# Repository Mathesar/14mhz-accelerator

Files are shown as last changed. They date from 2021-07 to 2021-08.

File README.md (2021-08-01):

# 14mhz-accelerator

This is 14MHz 68000 accelerator with 1MB fast ram and disable switch for the Amiga.
Tested on a rev. 5 Amiga 500. It might also work on other revisions and Amiga models but that has not been tested.
The design is licensed under CERN OHL-S V2.0

The design is a complete overhaul of a design by Livio Plos and Jorg Richter. Although based upon that design so much has been changed that it is almost like a new design.

Changes include:
* New clock doubler using an old school 4046 PLL to generate the 7MHz quadrature clock
This is more reliable than the RC delays in the original design. Alternatively the quadrature clock can
be taken from the motherboard. The latter has not been tested
* 3 input NOR's have been replaced by more common 2-input NOR's
In the process the basic design could be reduced to 4 IC's.
* some JK flipflops have been replaced by D latches.
* The E vs VMA/VPA timing has been improved for more robust write timing
* AS is now delayed before being fed to the motherboard fixing issues when the CPU does a chipset cycle after a CIA cycle.
* an optional 1Mb of zero waitstate Ranger RAM has been added to take full advantage of the 14MHz cpu.
* an optional reset timing based switch has been added to disable the ranger RAM upon boot.

## Variants
The accelerator can be build in 3 variant:
* Accelerator only
This only doubles the clock of the CPU to 14MHz. 
* Accelerator plus 1MB zero waitstate ranger RAM
The above but adds 1MB of fast RAM. This makes the accelerator about 2.7 times faster than a stock A500
* Accelerator plus 1MB zero waitstate ranger RAM plus disable circuit
The above but adds a timer based disable option for the RAM. By holdiing ctrl-amiga-amiga down for more 
than 5..6 seconds the RAM is disabled. It is enabled again on the next (less than 5..6 seconds) reset cycle

## Building hints
* use turned/machined pins only for the host connector!
The thick part is soldered on the accelerator, the thin part goes into the 68000 socket on the motherboard.
Makes sure to use the full length of the pins (only solder the tips in the accelerator board) so the accelerator sits above the Kickstart.
* an MC68HC000 (HCMOS version) is preferred as it uses less power and has better drive. This might also help with EPROM Kickstarts on a rev. 5 motherboard.
* The PLL might needs some tuning to provide a 50% dutycycle clock. 
Tuning is done by making the value of R3 slightly smaller or larger until testpoint J2 shows a nice
50% / 14MHZ clock signal. An oscilloscope works best here but alternatively a simple multimeter can be used to adjust the DC voltage
to read half the VCC value. (thus typically about 2.5V if VCC is **really** 5V)
* Alternatively the CDAC signal from the motherboard can be used. No tuning needed but untested at this point.

Here is a picture of the most basic variant (accelerator only) for reference purposes:
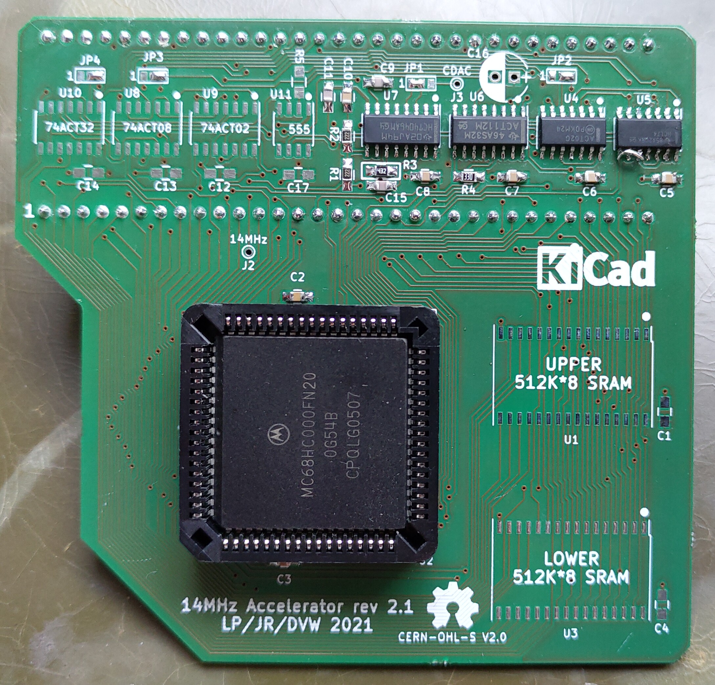
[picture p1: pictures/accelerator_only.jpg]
Accelerator only


And here a picture of what a complete build should look like:
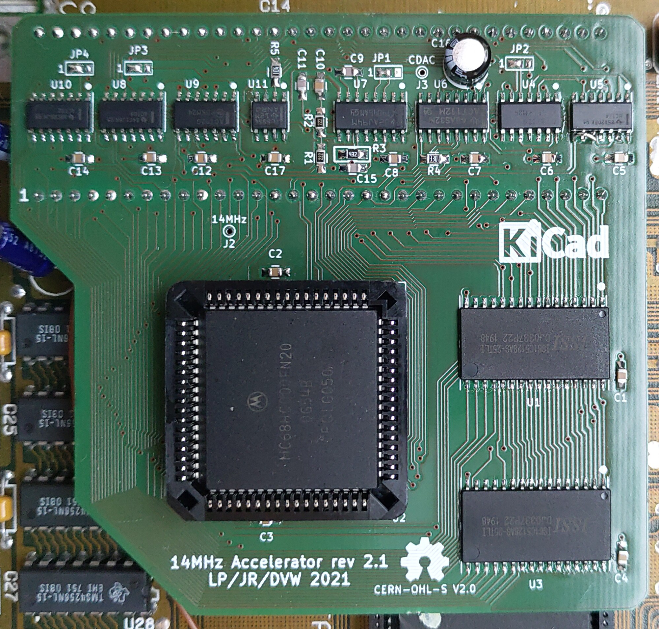
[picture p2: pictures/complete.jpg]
complete build


Have fun!

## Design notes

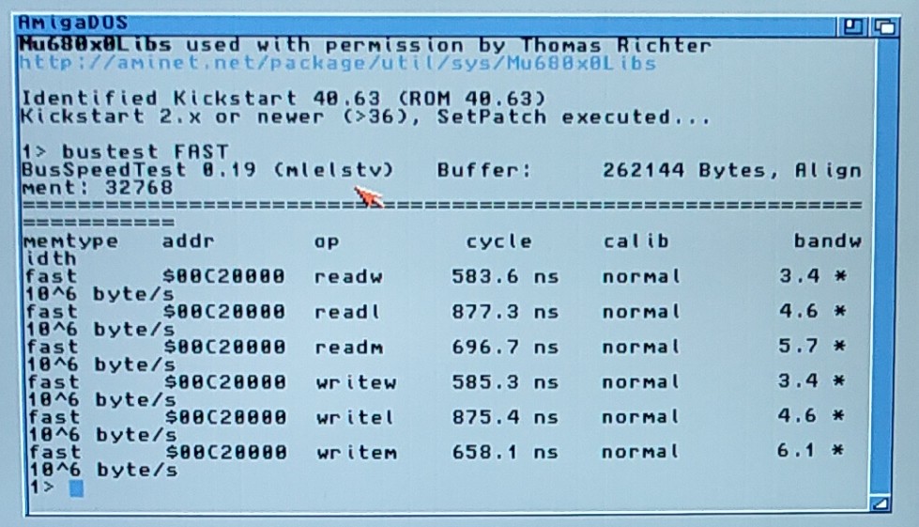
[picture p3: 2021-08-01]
pictures/IMG_20210704_210522~2_copy.jpg

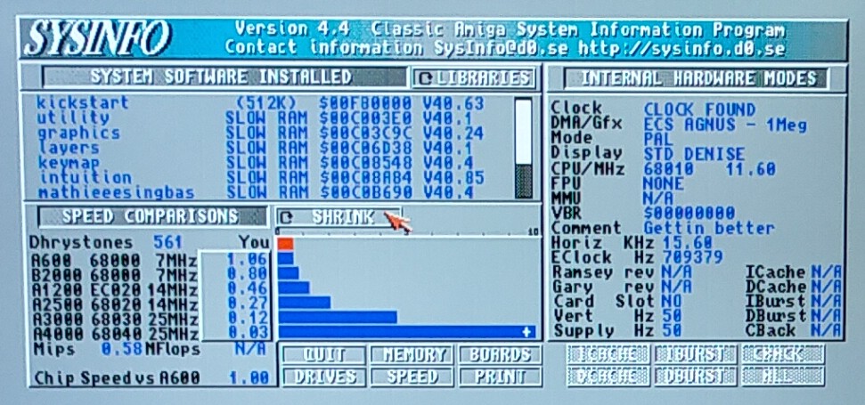
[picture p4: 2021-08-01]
pictures/IMG_20210704_210146~2_copy.jpg

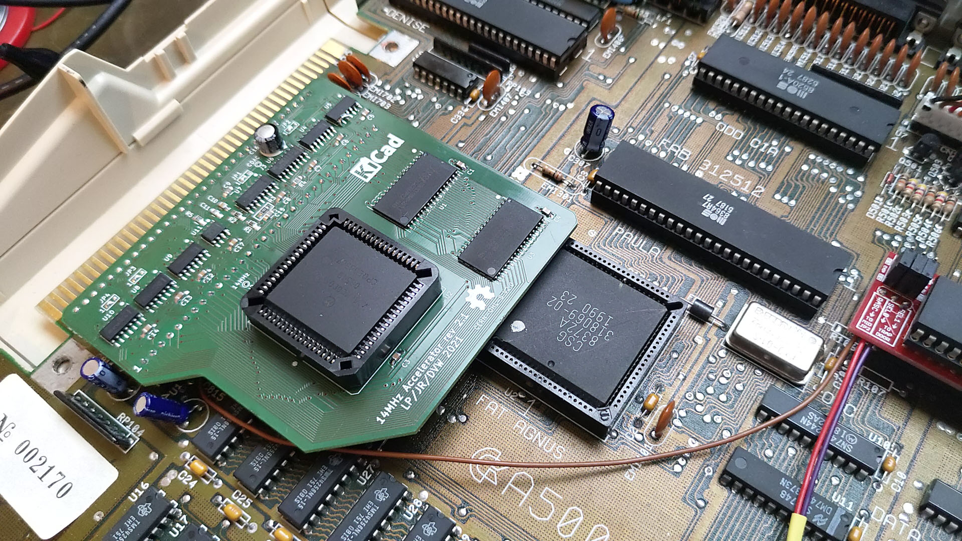
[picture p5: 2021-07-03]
pictures/mounted in A500.jpg

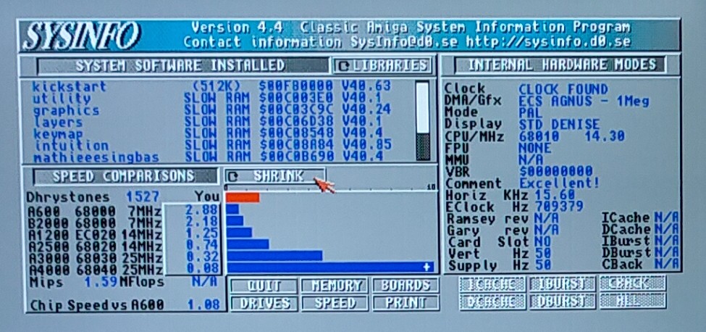
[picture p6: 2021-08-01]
pictures/IMG_20210704_205705~2_copy.jpg

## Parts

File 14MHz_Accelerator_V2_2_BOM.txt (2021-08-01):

RefDes		Partnumber	Remarks
#####################################################################################

U1,U3		512K*8 SRAM	IS61C5128AS-25TLI or similar 5V type

U2		MC68HC000	PLCC-68 Thru Hole socket 

U4,U9		74ACT02		U4 can be 74HCT02

U5		74HCT74		must be HCT

U6		74ACT112	

U7		74HCT4046	also 74HC4046 if CDAC not used

U8		74ACT08		

U10		74ACT32		

U11		TLC555CD	or any other CMOS 555

J1		2 * 32pinstrip	machined pins only. for example 2 * TS-132-T-A 

C1,C2,C3,
C4,C5,C6,
C7,C8,C10,
C12,C13,C14,
C17		100n		0805 

C9,C15		100p		0805

C11		22p		0805

C16		47u/16V		2.5mm radial 6.3mm dia

R1,R2		2K2		0805

R3		4K3		0805 (might need tuning)

R4		33 Ohm		0805	

R5		100K		0805

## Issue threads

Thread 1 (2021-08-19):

Jumper On U5

ozkanocakli, 2021-08-19:
is it a fix, or is it a  temporary jumper that forgot on it

Mathesar, 2021-08-20:
The pictures are from revision 2.1. That revision need a small patch hence the jumper wire on U5.
The current design is revision 2.2 fixed that issue and needs no patches or jumper wires to work.

ozkanocakli, 2021-08-20:
Thanx,

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

Closed 2021-08-20.

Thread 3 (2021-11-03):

Other address range for A600/2MB Chip-RAM compatibility?

Lalarian, 2021-11-03:
Hello!

I wondered, if it would be possible to add a jumper for changing the address range?
While was searching for affordable solutions, for making the A600 a capable WHDLoad machine (which would require FastRAM and an 68010 for the quit-key-feature), I was also including A500 expansions into the search, since
there are cheap adapters that disable the A600's onboard 68k (like Lemaru's PLCC2DIP), which allow plugging 68K DIPs into the A600.

So I found a video about your new accelerator on YouTube and then the thread on abime.
There I read you used the ChipRAM range for not having to bother with autoconfig.
Putting an 68010 in the socket of this board shouldn't be a problem, as it's fully compatible.

So the only problem would probably be the conflict with an A600 that has 2MB ChipRAM overall from the trapdoor slot.
I think autoconfig isn't too important (is it?), as we could automatically add the RAM of the board from startup-sequence/user-startup, using Amiga's 'addmem' tool, which would basically always be possible, when booting the user's own system from HD/CF/SD before starting WHDLoad.

So, would it be possible to place the board's RAM as 8MB-FastRAM from 0x200000 to 0x9FFFFF? Maybe just by swapping some address lines around using a jumper (as this project is of course intended to stay affordable)?
Thank you! :)

Mathesar, 2021-11-06:
Hello Lalarian,

The 1MB ram on this board is assigned the $C00000. The optional 1MB chipram in the A600's trapdoor slot is assigned to $100000. So there should be no conflict!

Lalarian, 2021-11-06:
Thank you! That's great news!
So I am gonna try to upgrade my 600, soon! I will report when I'm done, just for confirmation!
:)

Closed 2021-11-06.

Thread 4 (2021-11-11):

Platform agnostic?

dlxmax, 2021-11-11:
Is there anything that would keep the accelerator-only version from working on another 68k platform, such as a Mac or Atari?

Mathesar, 2021-11-14:
Probably only the RAM. I don't know the memory layout of the ST or the Macintosh but I can imagine that the $C00000..$CFFFFF range is already taken. Other than that I see no fundamental reason why it wouldn't work. Best way to find out is to try it out with an accelerator-only version.

dlxmax, 2022-01-12:
I measured for putting one of these in a Mac Plus, but the board is at least 3mm too long to fit, interfering with the power connector. Trying to beat it with height would result in case interference. I suppose the PCB could be shaved at the bottom, as it appears those lines are for the memory chips...but that's such a dirty hack lol. I really hoped to give it a go!

Closed 2022-02-10.

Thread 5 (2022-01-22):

Disable switch?

MarkieV, 2022-01-22:
Hi there

In the readme it says 'and disable switch for the Amiga' I looked several times at the schematics,
but I can not find a switch.
Do I have to make something with two 74F157 switches (like in the old version) to switch between
7MHz and 14MHz? or do I overlook something.

I would like to make a small PCB that sits under the 68000 with only the clock doubler as I already
have 8MB fastram.

Grtzz  Mark

Mathesar, 2022-01-25:
On page 3 of the schematic you can see a 555 timer based circuit. This is the disable switch that works by holding ctrl-amiga-amiga key combo down for more that 6 seconds or so.
However, it does not disable the clock doubler but only the ranger (fast) ram. In practice this has virtually the same effect as disabling the clock doubler.

Mathesar, 2022-01-25:
One more thing. Combining this accelerator with fast ram sitting on the Amiga bus will not be very fast as that ram does not run at the full 14MHz. My guestimate is that it will make your Amiga about 1.5 times faster than stock.
(based on this text: [http://www.cucug.org/amiga/amiinfo/reviews/Accelerator14M.txt](url)

Closed 2022-01-25.

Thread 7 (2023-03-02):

Sysinfo shows CPU@11.30 Mhz and not 14 Mhz.

felmur, 2023-03-02:
Hi Mathesar and thanks for this beautiful project.

I had the PCB made by PCBWay, then I ordered the components for the accelerator only (CPU and the 4 ICs and those few smd passive components).
After having soldered everything, I tried to mount it in my A500 rev6, already equipped with this ram expansion, 2MB version (0.5 chip, 1.5 fast):
https://amigastore.eu/en/710-amiga-500-512kb2mb-memory-expansion-rtc.html#/
When I run SysInfo it calculates a clock speed of 11.30 Mhz (and not 14 Mhz) and a very small increase in performance (1.04 vs A600).
What do you think?
Regards.

Mathesar, 2023-03-03:
Hi Felmur,

The 2MB trapdoor expansion from amigastore.eu gives you 1.5MB "pseudo" fast RAM. Not real fast RAM. As a result the 14MHz CPU can not run at full speed. This accelerator only reaches its full speed when the 1MB of local fast RAM is also populated. Without it, you will only see this small speed increase that you see now.

felmur, 2023-03-03:
Hi Mathesar,
In fact, by removing the expansion, the speed measured by SysInfo goes up to 11.70 Mhz and the performance goes up to 1.05 vs A600. Nothing changes if I use the PC CDAC instead of the accelerator internal clock.
If so, it's not worth using this booster without installing ram memory as well.
Well, patience. Thanks for the reply.

Mathesar, 2023-03-03:
I wouldn't really worry about 11.70 MHz vs 11.30 MHz, that is just noise.
The RAM expansion won't make your system slower. You can install the RAM memory on the accelerator board and still use the 2MB expansion. However, the first 1Mb of slow ram won't be used anymore as it will be overruled by the accelerator RAM.
So, you keep the same amount of memory (2.5Mb total) but the first 1Mb of slow RAM will turn into real fast RAM.

felmur, 2023-03-03:
Thanks Mathesar, I had already started looking for the rest of the components to complete the accelerator + ram.

felmur, 2023-04-24:
Due to an error in the order of the remaining components from Chinese companies, I had to wait until today to be able to finish the accelerator, which I just did. And... It Works! Sysinfo tells me that my A500 is now 2.70 times faster than an A600 and 1.22 times faster than an Amiga1200. Thanks for this wonderful project!

Mathesar, 2023-05-03:
Good to hear!
Enjoy!

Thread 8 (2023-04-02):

simple 8MB option (AS6C6416)

raszpl, 2023-04-02:
AS6C6416 https://www.alliancememory.com/wp-content/uploads/pdf/Alliance%20Memory_64M_AS6C6416-55TIN%20v1.0%20July%202017.pdf
3.3V only (max Vcc 4.6V) so author of Parciero went full insane mode https://hackaday.com/2021/01/08/the-amiga-1000-still-receiving-new-peripherals-35-years-later/#comment-6309849 but it works. To be on a safe side there should be $1 SN74LVC16T245 in front of it.
$28 so not terrible https://www.digikey.com/en/products/detail/alliance-memory-inc/AS6C6416-55TIN/7791412 considering two IS61C5128AS is already $10.

Mathesar, 2024-08-13:
Could be done I guess. The address decoder has to be changed of course, as well the RAM CS  and OE / WR strobes as these are currently layed out for a high byte and low byte RAM chip. Also, the RAM would have to be added via a command in the startup sequence as it will not be auto recognized.

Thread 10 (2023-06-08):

Compatible with trap door 512k RAM expansion on A500?

alexispurslane, 2023-06-08:
I'm brand new to this stuff, and reading through the forum thread where this project was introduced, it seemed like this board puts the onboard RAM in the same address location as slow RAM, which would override the slow RAM trap door expansion, while also not _really_ being slow RAM, meaning it isn't accessible to the chips, thus limiting my machine to 1.5MB instead of 2MB, and (more importantly) making it impossible to do the Fat Agnes ECS mod to my A500 if I'm using it. Is this right or am I completely off-base? I think I'm probably wrong given your sysinfo screenshot.

Also, I recently bought a print of this board (and some ICs) off eBay, and it comes with a 68020, has anyone had any luck with using an 020 with this board before?

alexispurslane, 2023-06-09:
Closed bc answer is obvious: 020 won't work (I misread what I'd bought anyway), and yes, the 1MB of "slow" fast RAM on the board will shadow the 512k of slow RAM in a trap door expansion, so best to turn that into chip RAM with the Obese Agnus ECS mod.

Closed 2023-06-09.

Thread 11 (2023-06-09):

Is this compatible with *any* internal hard drive IDE expansion/card/etc?

alexispurslane, 2023-06-09:
If the issue with the A590 is DMA and it having its own fast RAM, won't that be an issue for any hard drive?

Mathesar, 2024-08-13:
Don't know really. It works with harddrive adapters of my own design (non-booting IDE and SD) but I haven't tested it with any other devices. The only issue for sure has to do with DMA. Other issues (if any) will have to be found out.

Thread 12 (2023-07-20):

enhancement: 16bit ram chip support

pluspeople, 2023-07-20:
Love the design (despite the DMA issue), would it be possible to enhance the design to utilize 16bit sram chips instead of 2x 8bit chips ?
This would give the following advantages:
- It would be possible to fit 2x 4mbit 16bit chips (1.75 addressable) without having to increase pcb size (ok tsop-44 is 5mm longer than tsop-32)
- One could choose to install either 1 or 2 chips (more options / choice)
- If only 1mb is wanted as then only one ram chip needs to be fittet (enhanced simplicity)
- As of writing a 4mbit 16bit chip costs 7.07euro vs 8.50euro for 2x 4mbit 8bit chips (slightly cheaper)

As an example I have been looking at the AS6C8016-55ZIN chip which is 5v compatible, and 55ns speed (I believe it only need to be 70ns or better to work fullspeed at 14mhz?)

Mathesar, 2024-08-13:
As commented in another issue, it could be done. However, quite some stuff would need to be changed. The address decoder has to be changed of course, as well the RAM CS and OE / WR strobes as these are currently layed out for a high byte and low byte RAM chip. Also, the RAM would have to be added via a command in the startup sequence as it will not be auto recognized.

Closed 2024-08-13.

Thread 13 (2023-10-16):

Newly built, no 1mb ranger memory reported

opengiveback, 2023-10-16:
Hi, thanks for the design.

I built one configured with all the circuits, and it worked right away. However, no ranger RAM is being reported, and measuring voltage on J2 always gets me 2.57V.

Then I found, my jumper JP2 wasn't soldered properly (all three shorted), and some solder was shorting pins of U4. However, after fixing it, still does not have any of the accelerated RAM, 1.10 max speed improvement to Amiga 600 in SysInfo, and reports 12MHz consistently.

I'd have to ask, the possibility of RAM itself not working is not what is causing the ranger RAM not to be there, right? It's some logic IC that actually reports the ranger RAM on init that's at fault? And if the RAM was faulty, it would simply freeze?
Or should I try with other RAM chips?
Or perhaps, something else entirely needs to be done to make it work? All the jumpers are shorted at pin 1 (left).

Thanks in advance

P.S. I intend to build and sell at least 10 of them, and give back 15% of the profit to the author, as per my OpenGiveBack.org idea :)

Mathesar, 2023-10-16:
The Amiga scans the ranger memory during boot time. So as it is not detected it does not use it. The computer won't freeze.
I would suspect the logic IC's that decode the memory addresses for the memory so U8/U9/U10. Check all solder joints, shorts, etc. It could also be the NE555 circuit that disables RAM. What is the level on pin 3 of U11? It should be low. You could also try setting JP4 to 2-3 for testing to disable the NE555 circuit.

opengiveback, 2023-10-18:
Triple checked all/touched up on all the relevant solder joints, pin 3 of U11 showed 0.05V (or was it 0.5V), so low, and also disabled NE555 by setting JP4 to 2-3. And the ram still was not there upon booting.

Then I changed the memory chips, for the other ones I ordered (was ALLIANCE AS6C4008-55SIN chips, then tried with HM628512CLFP-7). With the JP4 set to 2-3. And still the same result as at the start, Accelerator works, but none of the ranger RAM detected.

So, I guess the only conclusion is, some logic circuit is not working (U8, U9, U10), and needs to be replaced?

Could I test at least the NE555 by having 512KB slow RAM in expansion slot, and trying to see that slow RAM reported when holding reset keys for 6, 7 seconds, and JP4 is set to 1-2? (Because I couldn't see it before, whether held the combination for 7 seconds or not)... It should have the expansion port slow 512KB ram working now when the JP4 is set to 2-3, correct? And yet, it again boots into workbench and shows only the 512KB chip RAM, in AmiTestKit and SysInfo also. I cant understand why that would be? A pin in the CPU socket perhaps, but they all were crisp as was the ones on the new MC68HC000....

I shall try soldering another example on a different PCB, to rule out PCB manufacturing faults or a single logic chip of the ordered batch being faulty. But if you have any idea on what could be the problem with this one, I would appreciate it highly.

opengiveback, 2023-10-18:
After checking on the type of memory chips, the one you listed in the BOM is a TSOP II, and both of these are TSOP I (sTSOP), the pinout is very different. So it seems it was wrong type of memory chips that was the issue. First chose wrong extension of the model, then ordered alternative for wrong chip. Surely the wrong pinout also causes the problem with unadressable expansion port slow RAM.

I see other manufacturers have same pinout in sTSOP and TSOP II... actually the HITACHI HM628512C I used, has almost same pinout as the ISSI IS61C5128AS-25TLI from the BOM, except address lines A18 and A17 are in each other's places, which being 8 bit memory I didn't think it should matter. So I shall make another example with the HITACHI chips, and see how that goes...

opengiveback, 2023-11-20:
Update, resoldered RAM chips, stopped turning on, unsoldered them again, started working without RAM again. Soldered another, with new chips, presoldered pads, more careful to be sure all pins connected good, the other example refuses to turn on also, black screen, waiting for some Cypress chips from your forum link to arrive, with exact dimensions.

opengiveback, 2023-11-28:
Hi, so the Cypress RAM arrived, soldered it on, now all works great! :)

Thanks for the replies, and please disclose paypal email or similar means for me to donate the 15% of earnings from sold examples of this great design, as per OpenGiveBack.org.

Mathesar, 2023-12-02:
> Hi, so the Cypress RAM arrived, soldered it on, now all works great! :)
>
> Thanks for the replies, and please disclose paypal email or similar means for me to donate the 15% of earnings from sold examples of this great design, as per OpenGiveBack.org.

Hi Opengiveback,

You had quite a journey with your build. I'm sorry I couldn't check your RAM pinouts before you tried. But luckily it all works now!
And no donations please, this design is free!

Closed 2023-12-01.

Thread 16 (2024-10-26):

Confirmed working with an adapter on a A600

federicopitto, 2024-10-26:
Hello Mathesar. Thank you for this great project.

I finally got the accelerator working on his minimal configuration istalled on a A600 rev 1. It took me several tries and troubleshooting red herrings. I used LemaruX plcc to dip64 adapter to bridge the accelerator to the main board https://github.com/LemaruX/Amiga-A600-68k-PLCC2DIP-v2

Here's some photos of the setup and sysinfo

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

Sysinfo reports 18mhz but my cheap oscilloscope says the clock is at 14.20mhz

It was really difficult to tune the clock to a frequency stable enough to make the A600 initialize or complete the workbench boot. The diagROM ran no matter how unstable the clock, but the kickstart rom needed some fine tuning of the clock with the oscilloscope before even attempting to properly boot and read from the IDE device.
As you can see I installed a variable resistor in place of R3. Don't know if that was the cause oor the solution of my woes.

In my attemts, I tried using the CDAC signal directly soldering a wire from the motherboard to the proper accelerator input (and changing the jumper accordingy). I did not see any substantial difference in the stability of the input or the output.

A couple of notes:

Using version v2 of the adapter prevents the A600 case to close down.Version V1 of the adapter place the acceerator in a better spot, closer to the keyboar connector. The problem using that version is that V1 lacks the right screw-mount to clamp down the "vampire" socket tight enough against the onboard 68000 chip. I need to modify the adapter project and make it as long as the V1 version, but add back with the 4 screwmount needed to clamp it down to the HDD motherboard cutout.

I don't plan to have the ram installed right away as I want to test it further adding 4mb fastram through a PCMCIA ram card (still to be built). Alternatively I could fork your project and build the PLCC adapter directly to the accelerator board, but that may be a little too difficult considering my limited capabilities on circuit and PCB design.

Keep up the good work!

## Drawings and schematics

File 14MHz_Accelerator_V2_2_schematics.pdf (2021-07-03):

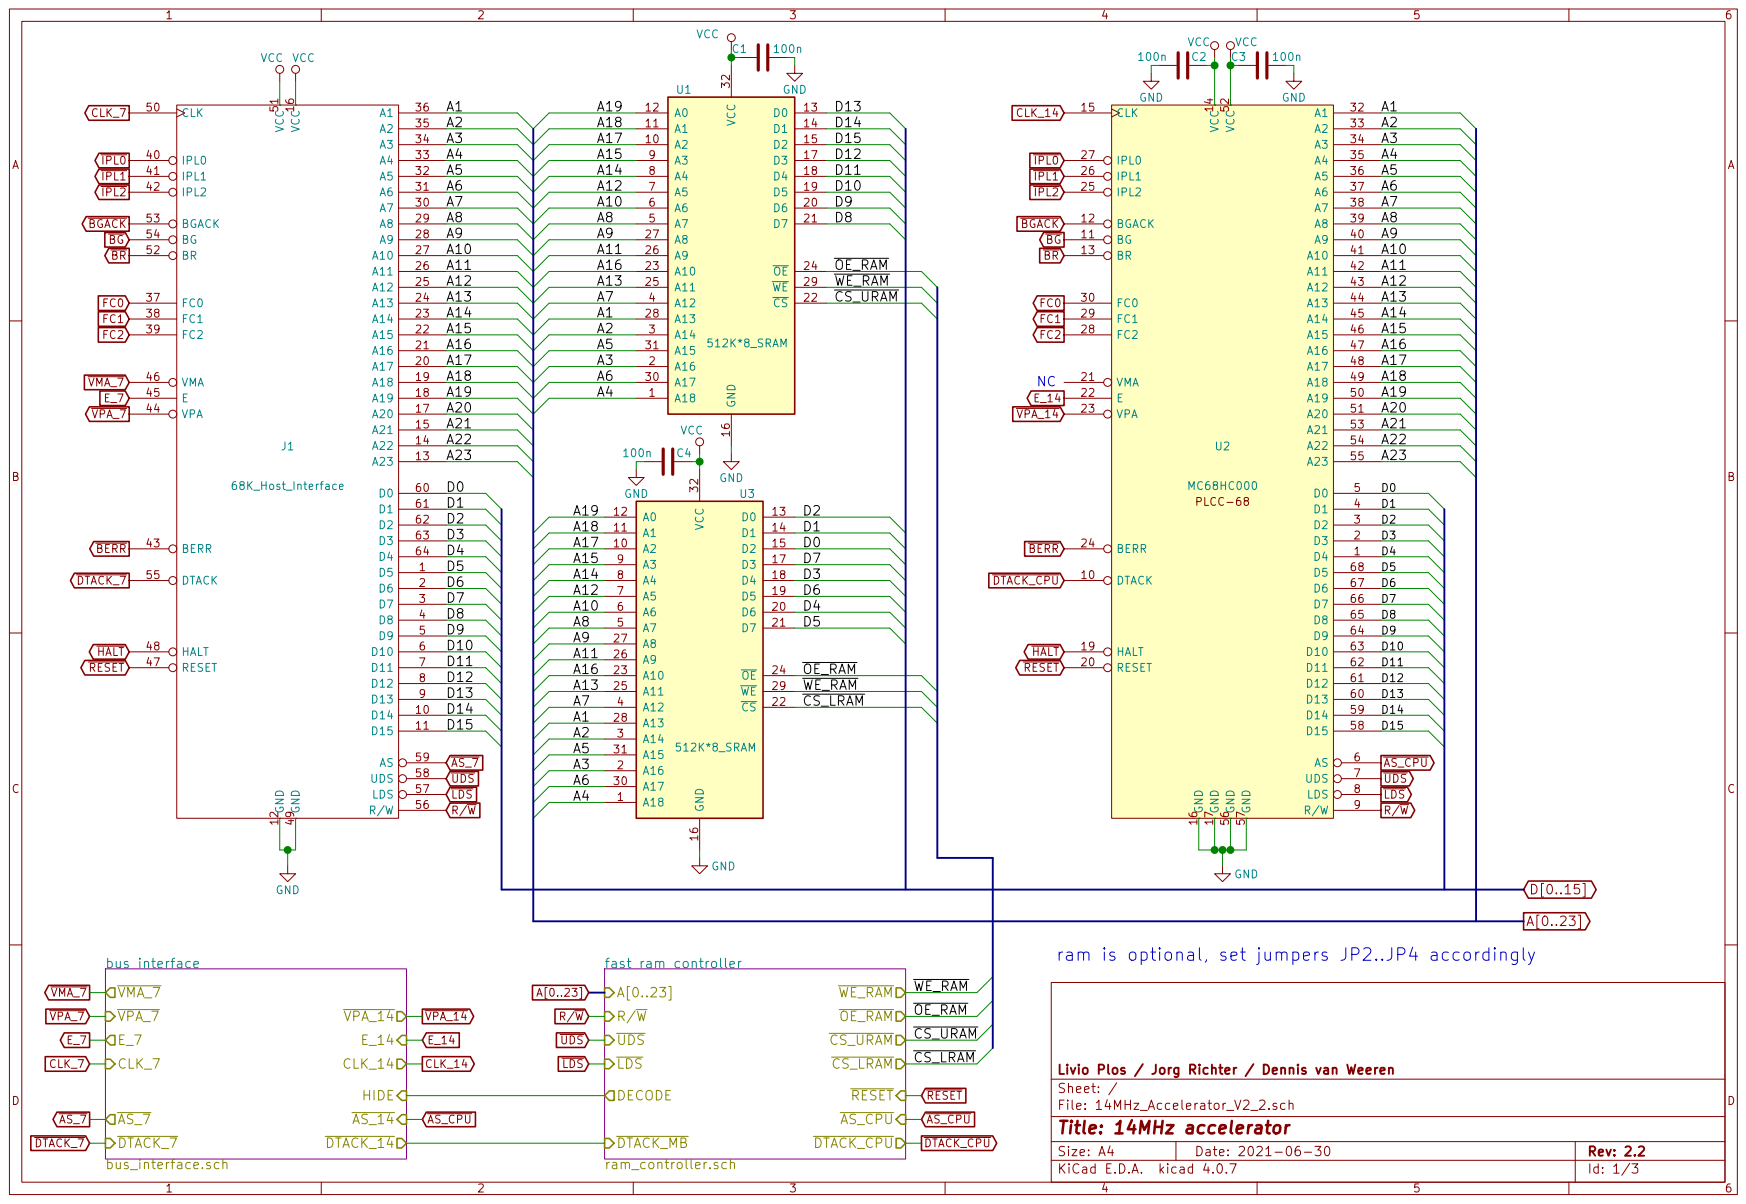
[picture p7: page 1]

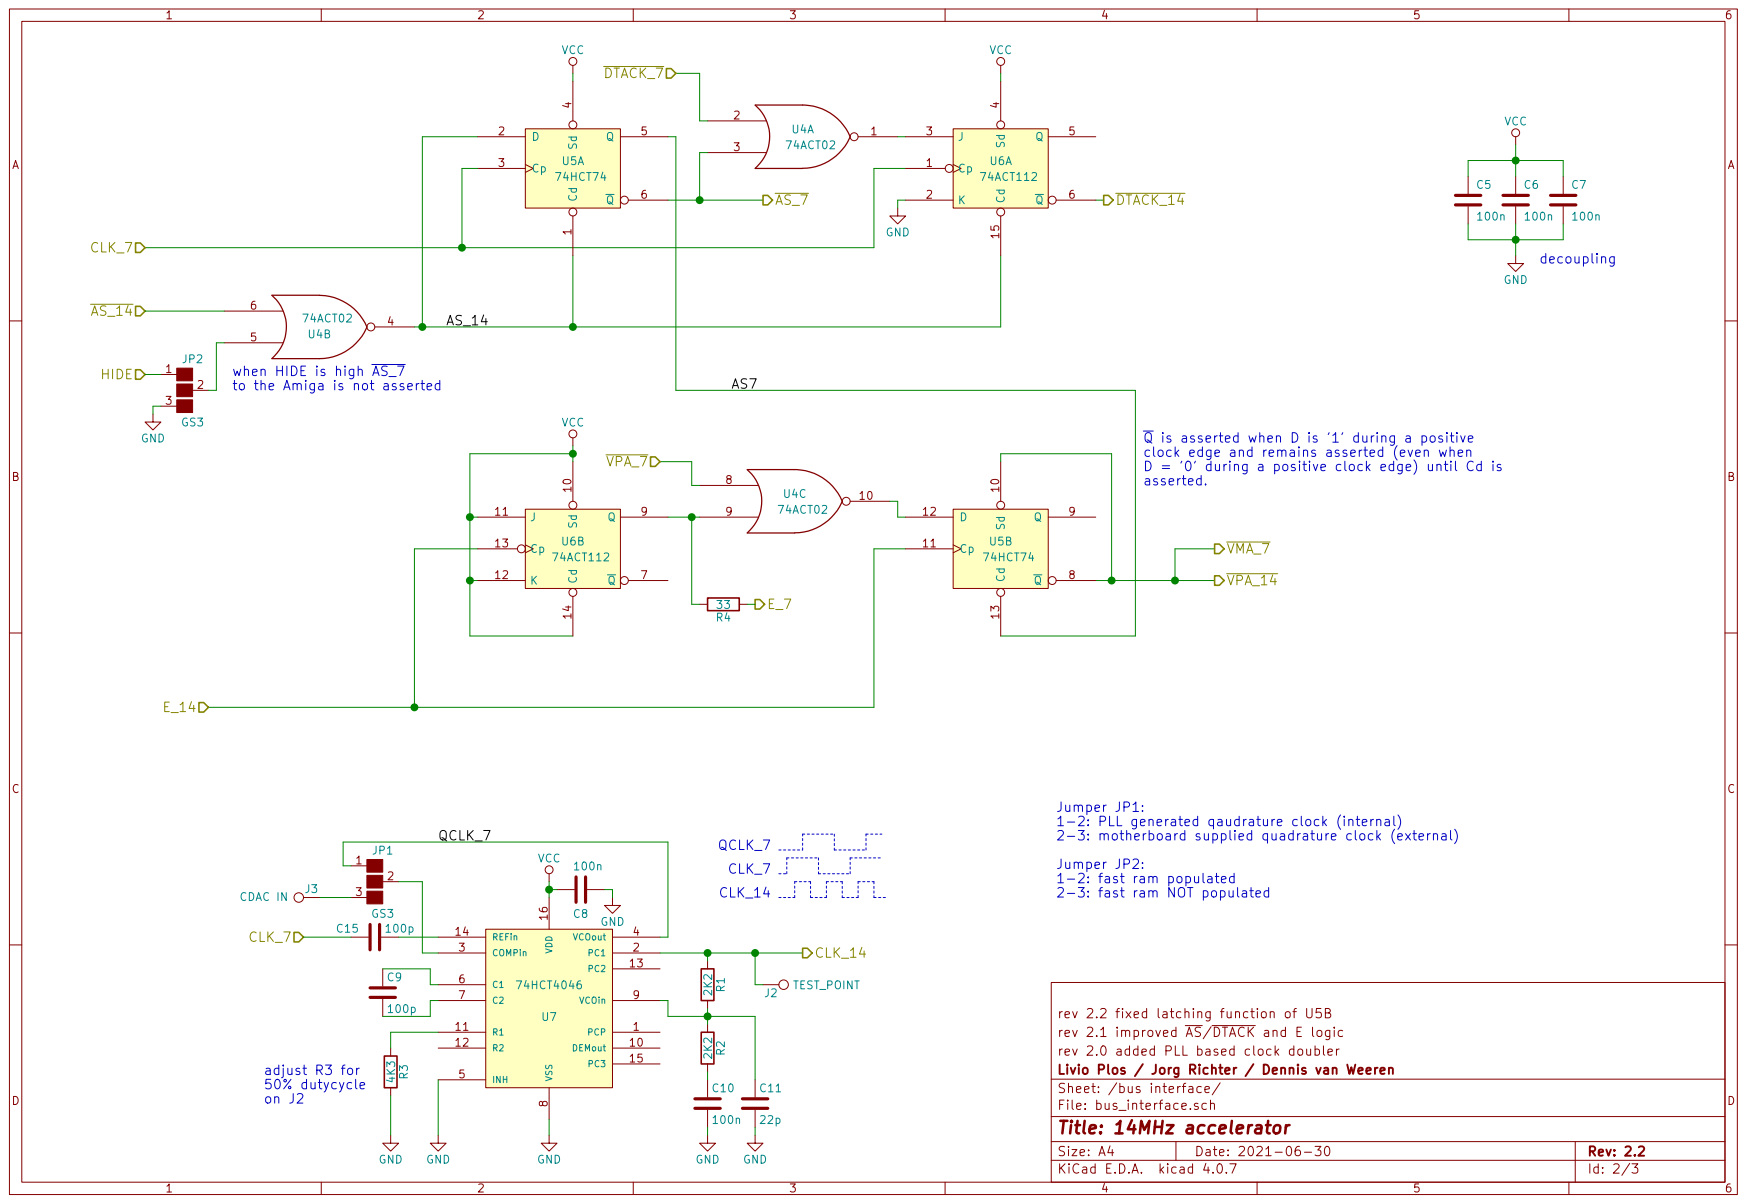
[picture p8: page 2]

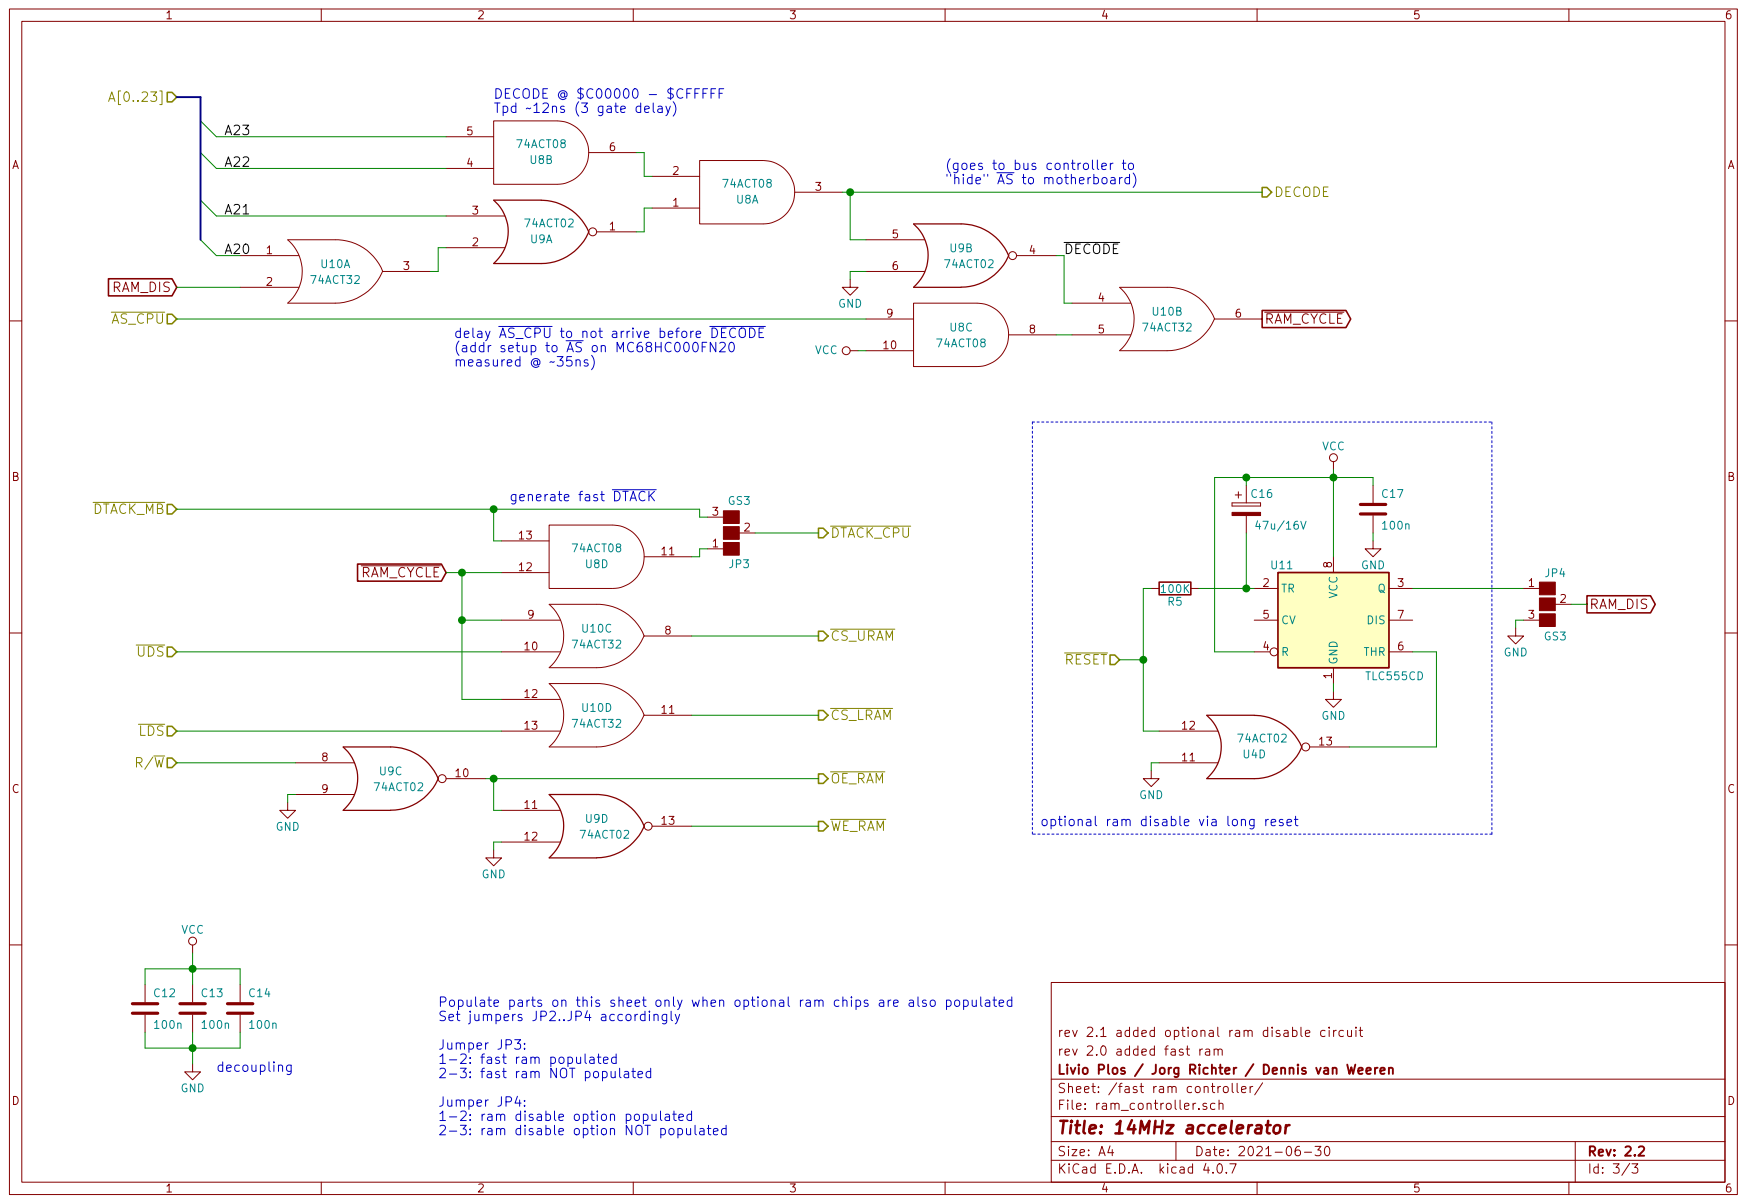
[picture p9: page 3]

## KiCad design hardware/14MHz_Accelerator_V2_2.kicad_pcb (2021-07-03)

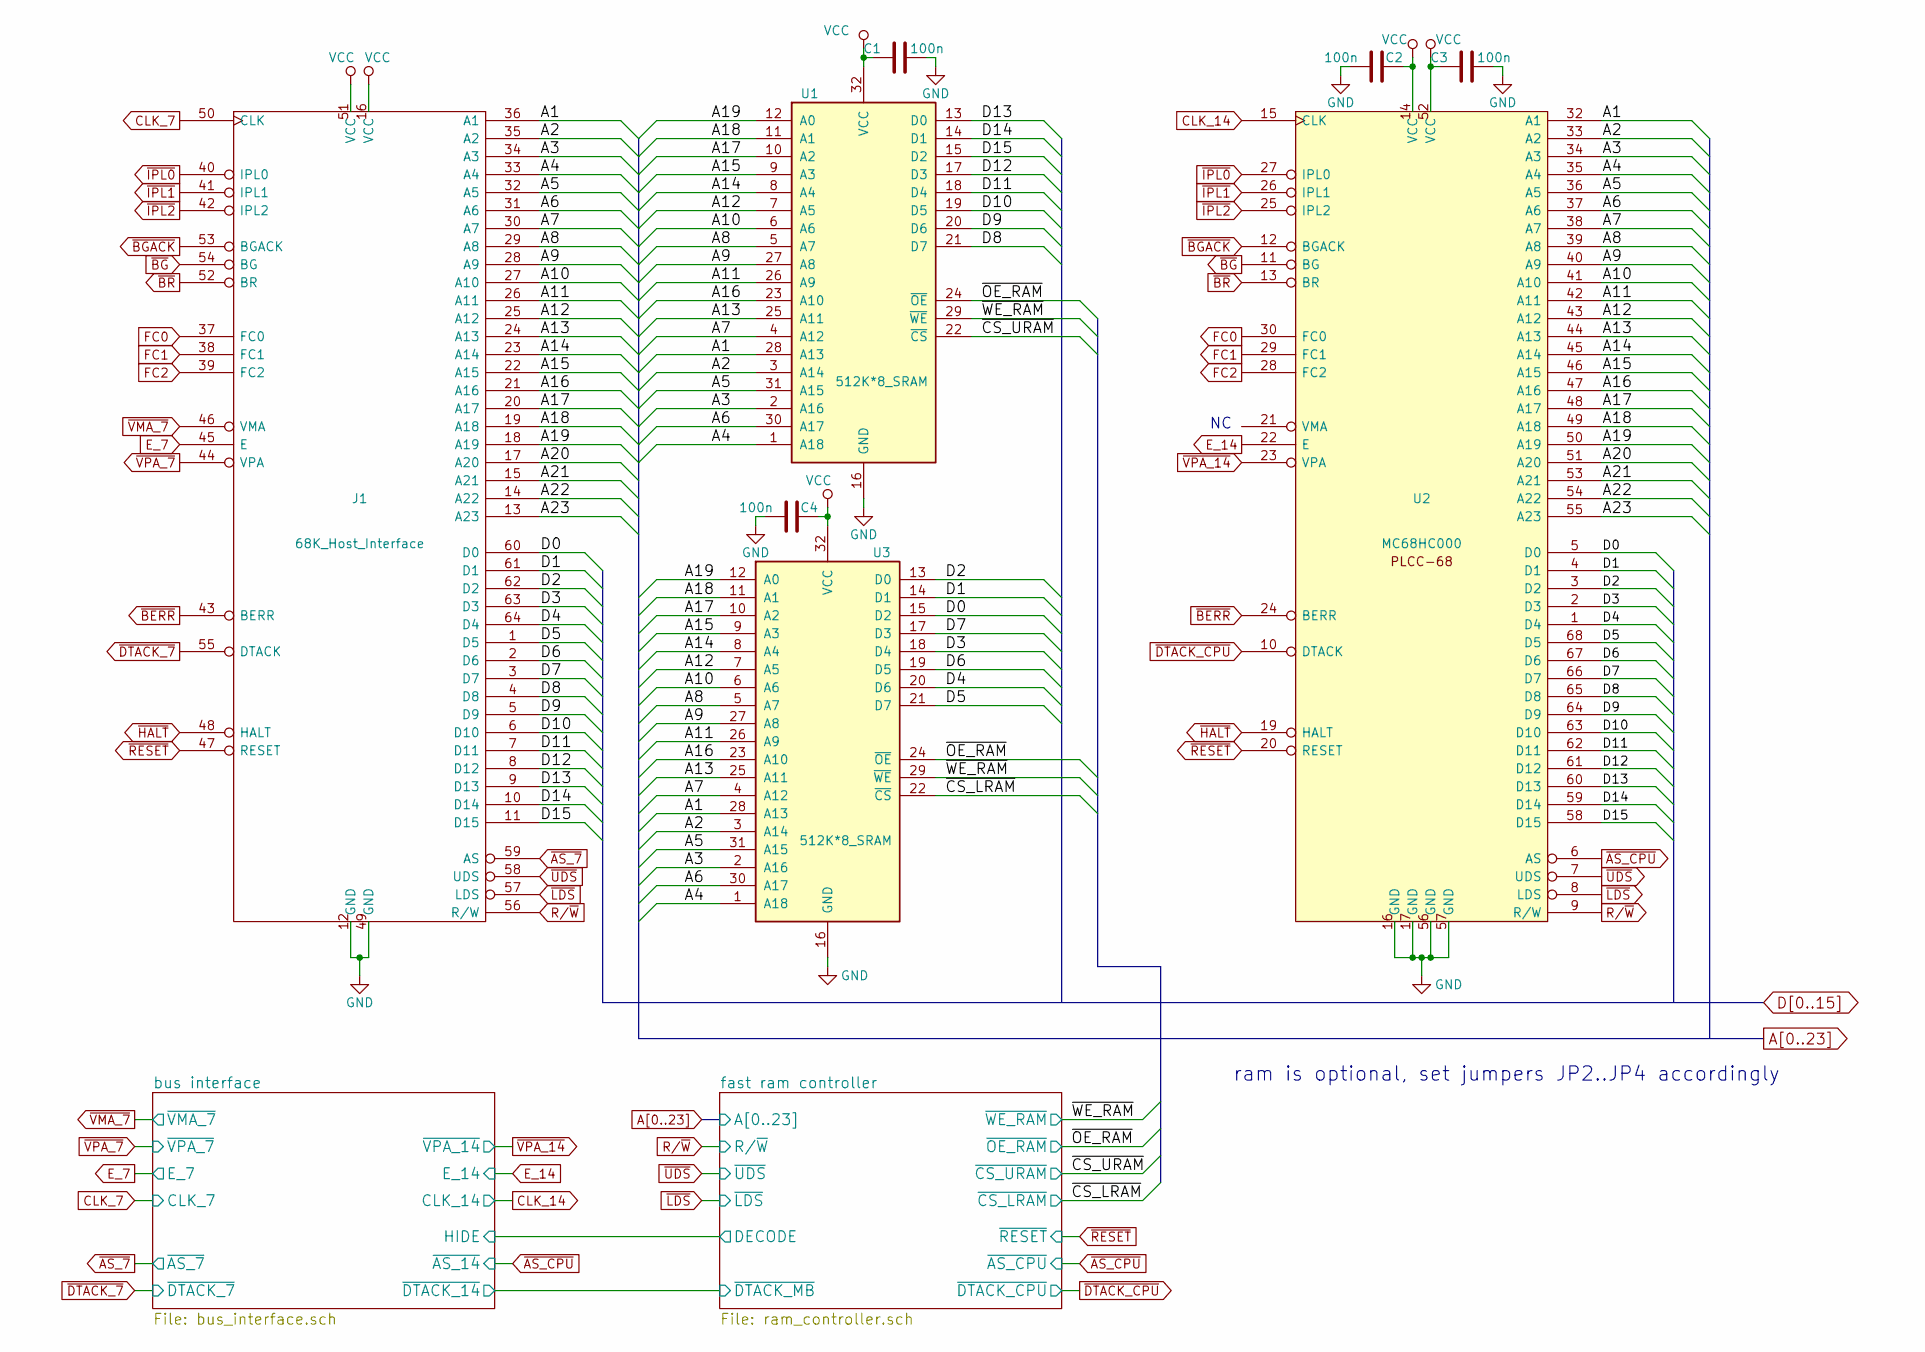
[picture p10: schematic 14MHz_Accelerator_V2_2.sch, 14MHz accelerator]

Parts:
C1, C2, C3, C4: 100n; C_0805_HandSoldering
J1: 68K_Host_Interface; DIP-64_W22.86mm
U1, U3: 512K*8_SRAM; TSOP-II-32_21.0x10.2mm_Pitch1.27mm
U2: MC68HC000; PLCC68_through_hole_socket

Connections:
/~CS_LRAM: U3.22 (~CS); also elsewhere on the board
/~CS_URAM: U1.22 (~CS); also elsewhere on the board
/~OE_RAM: U1.24 (~OE), U3.24 (~OE); also elsewhere on the board
/~WE_RAM: U1.29 (~WE), U3.29 (~WE); also elsewhere on the board
A1: J1.36 (A1), U1.28 (A13), U2.32 (A1), U3.28 (A13)
A2: J1.35 (A2), U1.3 (A14), U2.33 (A2), U3.3 (A14)
A3: J1.34 (A3), U1.2 (A16), U2.34 (A3), U3.2 (A16)
A4: J1.33 (A4), U1.1 (A18), U2.35 (A4), U3.1 (A18)
A5: J1.32 (A5), U1.31 (A15), U2.36 (A5), U3.31 (A15)
A6: J1.31 (A6), U1.30 (A17), U2.37 (A6), U3.30 (A17)
A7: J1.30 (A7), U1.4 (A12), U2.38 (A7), U3.4 (A12)
A8: J1.29 (A8), U1.5 (A7), U2.39 (A8), U3.5 (A7)
A9: J1.28 (A9), U1.27 (A8), U2.40 (A9), U3.27 (A8)
A10: J1.27 (A10), U1.6 (A6), U2.41 (A10), U3.6 (A6)
A11: J1.26 (A11), U1.26 (A9), U2.42 (A11), U3.26 (A9)
A12: J1.25 (A12), U1.7 (A5), U2.43 (A12), U3.7 (A5)
A13: J1.24 (A13), U1.25 (A11), U2.44 (A13), U3.25 (A11)
A14: J1.23 (A14), U1.8 (A4), U2.45 (A14), U3.8 (A4)
A15: J1.22 (A15), U1.9 (A3), U2.46 (A15), U3.9 (A3)
A16: J1.21 (A16), U1.23 (A10), U2.47 (A16), U3.23 (A10)
A17: J1.20 (A17), U1.10 (A2), U2.48 (A17), U3.10 (A2)
A18: J1.19 (A18), U1.11 (A1), U2.49 (A18), U3.11 (A1)
A19: J1.18 (A19), U1.12 (A0), U2.50 (A19), U3.12 (A0)
A20: J1.17 (A20), U2.51 (A20); also elsewhere on the board
A21: J1.15 (A21), U2.53 (A21); also elsewhere on the board
A22: J1.14 (A22), U2.54 (A22); also elsewhere on the board
A23: J1.13 (A23), U2.55 (A23); also elsewhere on the board
CLK_7: J1.50 (CLK); also elsewhere on the board
CLK_14: U2.15 (CLK); also elsewhere on the board
D0: J1.60 (D0), U2.5 (D0), U3.15 (D2)
D1: J1.61 (D1), U2.4 (D1), U3.14 (D1)
D2: J1.62 (D2), U2.3 (D2), U3.13 (D0)
D3: J1.63 (D3), U2.2 (D3), U3.18 (D4)
D4: J1.64 (D4), U2.1 (D4), U3.20 (D6)
D5: J1.1 (D5), U2.68 (D5), U3.21 (D7)
D6: J1.2 (D6), U2.67 (D6), U3.19 (D5)
D7: J1.3 (D7), U2.66 (D7), U3.17 (D3)
D8: J1.4 (D8), U1.21 (D7), U2.65 (D8)
D9: J1.5 (D9), U1.20 (D6), U2.64 (D9)
D10: J1.6 (D10), U1.19 (D5), U2.63 (D10)
D11: J1.7 (D11), U1.18 (D4), U2.62 (D11)
D12: J1.8 (D12), U1.17 (D3), U2.61 (D12)
D13: J1.9 (D13), U1.13 (D0), U2.60 (D13)
D14: J1.10 (D14), U1.14 (D1), U2.59 (D14)
D15: J1.11 (D15), U1.15 (D2), U2.58 (D15)
E_7: J1.45 (E); also elsewhere on the board
E_14: U2.22 (E); also elsewhere on the board
FC0: J1.37 (FC0), U2.30 (FC0)
FC1: J1.38 (FC1), U2.29 (FC1)
FC2: J1.39 (FC2), U2.28 (FC2)
GND: C1.2, C2.1, C3.2, C4.1, J1.12 (GND), J1.49 (GND), U1.16 (GND), U2.16 (GND), U2.17 (GND), U2.56 (GND), U2.57 (GND), U3.16 (GND); also elsewhere on the board
R/~W: J1.56 (R/W), U2.9 (R/W); also elsewhere on the board
VCC: C1.1, C2.2, C3.1, C4.2, J1.16 (VCC), J1.51 (VCC), U1.32 (VCC), U2.14 (VCC), U2.52 (VCC), U3.32 (VCC); also elsewhere on the board
~AS_7: J1.59 (AS); also elsewhere on the board
~AS_CPU: U2.6 (AS); also elsewhere on the board
~BERR~: J1.43 (BERR), U2.24 (BERR)
~BGACK~: J1.53 (BGACK), U2.12 (BGACK)
~BG~: J1.54 (BG), U2.11 (BG)
~BR~: J1.52 (BR), U2.13 (BR)
~DTACK_7: J1.55 (DTACK); also elsewhere on the board
~DTACK_CPU: U2.10 (DTACK); also elsewhere on the board
~HALT~: J1.48 (HALT), U2.19 (HALT)
~IPL0~: J1.40 (IPL0), U2.27 (IPL0)
~IPL1~: J1.41 (IPL1), U2.26 (IPL1)
~IPL2~: J1.42 (IPL2), U2.25 (IPL2)
~LDS: J1.57 (LDS), U2.8 (LDS); also elsewhere on the board
~RESET~: J1.47 (RESET), U2.20 (RESET); also elsewhere on the board
~UDS: J1.58 (UDS), U2.7 (UDS); also elsewhere on the board
~VMA_7: J1.46 (VMA), U2.23 (VPA); also elsewhere on the board
~VPA_7: J1.44 (VPA); also elsewhere on the board

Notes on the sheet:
ram is optional, set jumpers JP2..JP4 accordingly

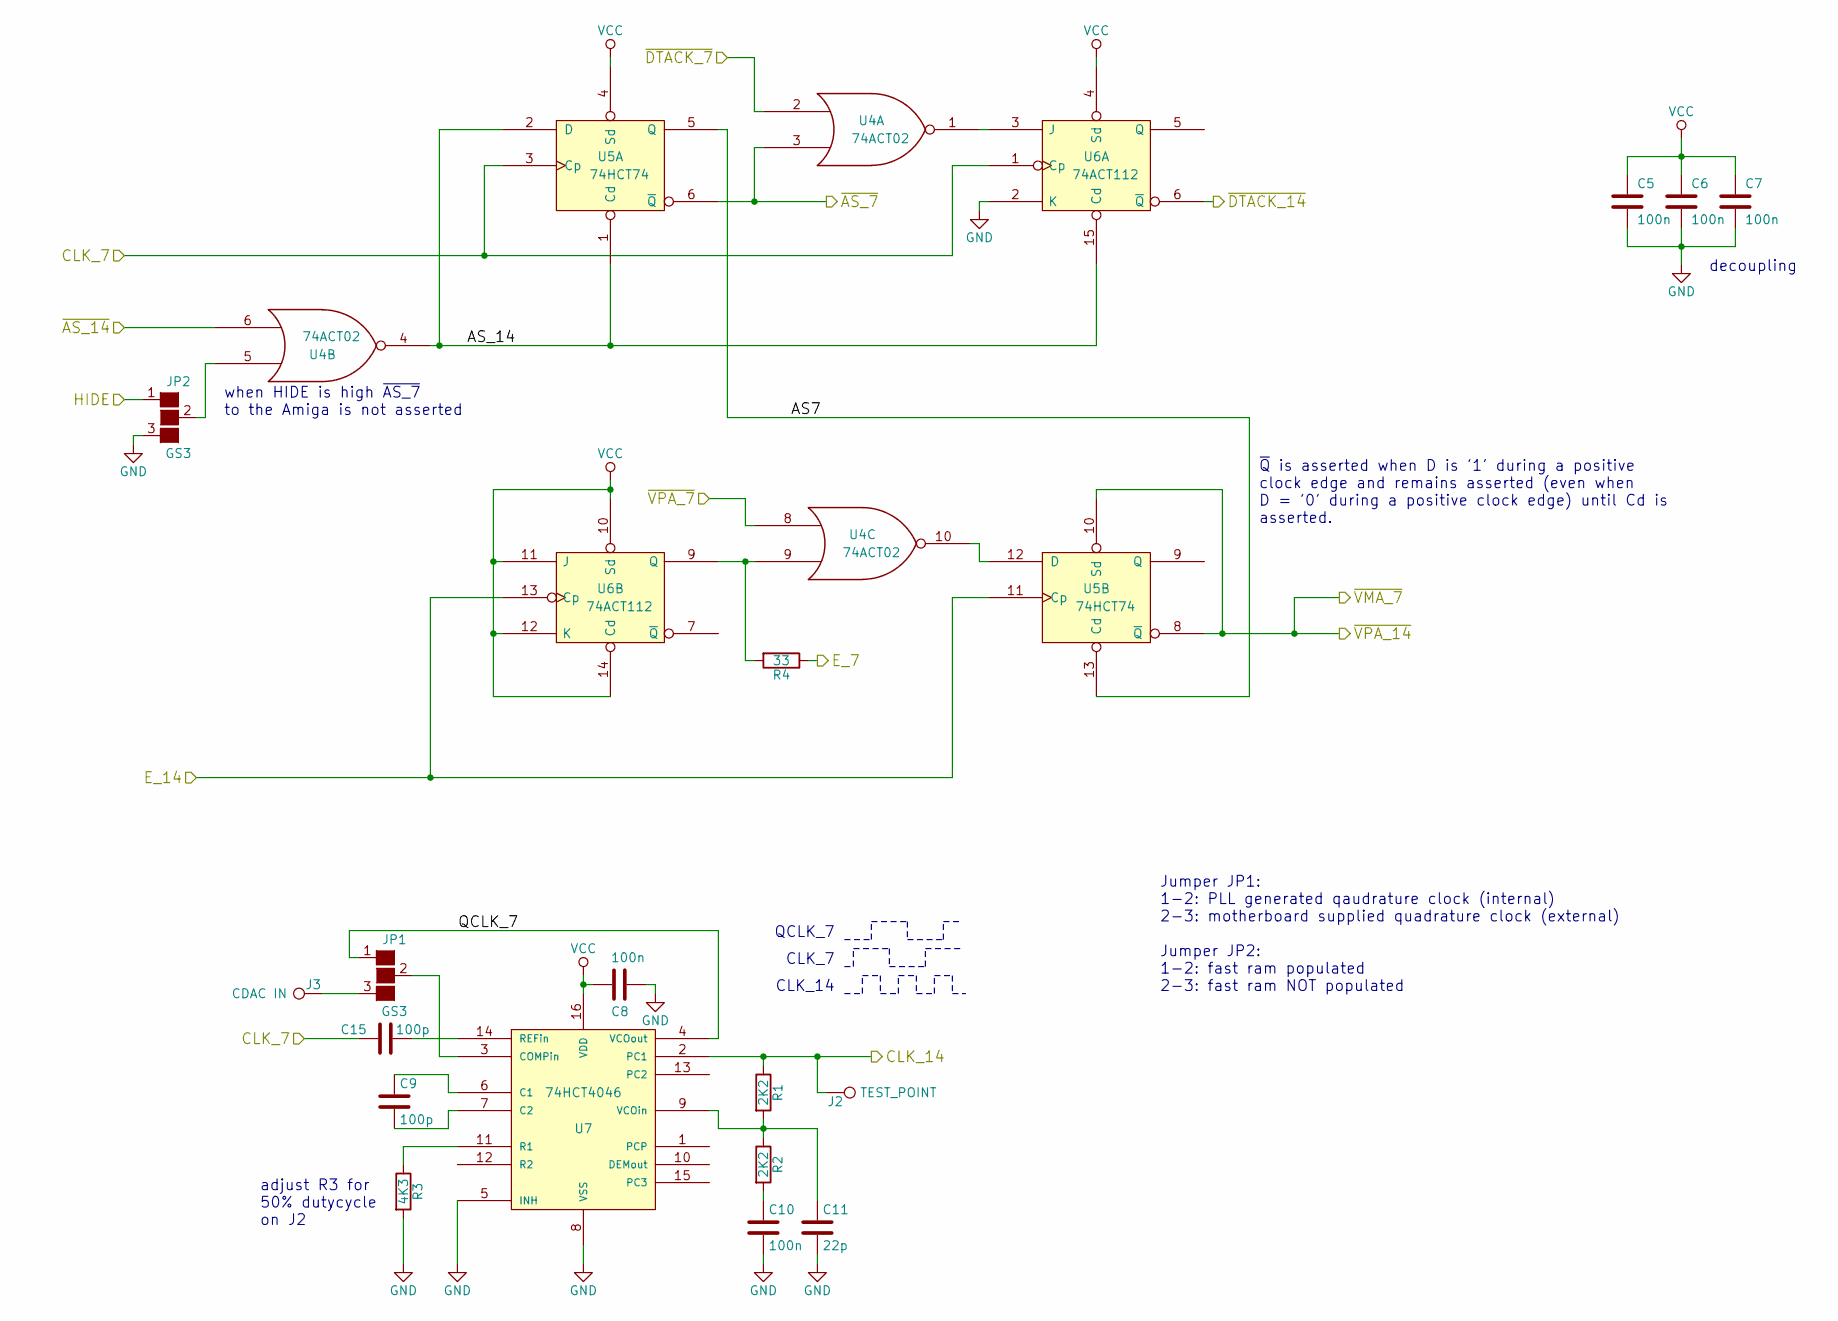
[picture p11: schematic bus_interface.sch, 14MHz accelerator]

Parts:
C5, C6, C7, C8, C10: 100n; C_0805_HandSoldering
C9, C15: 100p; C_0805_HandSoldering
C11: 22p; C_0805_HandSoldering
J2: TEST_POINT; PINTST
J3: CDAC IN; PINTST
JP1, JP2: GS3
R1, R2: 2K2; R_0805_HandSoldering
R3: 4K3; R_0805_HandSoldering
R4: 33; R_0805_HandSoldering
U4: 74ACT02; SOIC-14_3.9x8.7mm_Pitch1.27mm
U5: 74HCT74; SOIC-14_3.9x8.7mm_Pitch1.27mm
U6: 74ACT112; SOIC-16_3.9x9.9mm_Pitch1.27mm
U7: 74HCT4046; SOIC-16_3.9x9.9mm_Pitch1.27mm

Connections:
/bus interface/AS7: U5.5 (Q), U5.13 (Cd)
/bus interface/AS_14: U4.4, U5.1 (Cd), U5.2 (D), U6.15 (Cd)
/bus interface/QCLK_7: JP1.1 (G1), U7.4 (VCOout)
/bus interface/~DTACK_14: U6.6 (~Q); also elsewhere on the board
/fast ram controller/DECODE: JP2.1 (G1); also elsewhere on the board
CLK_7: C15.1, U5.3 (Cp), U6.1 (Cp); also elsewhere on the board
CLK_14: J2.1, R1.1, U7.2 (PC1); also elsewhere on the board
E_7: R4.1; also elsewhere on the board
E_14: U5.11 (Cp), U6.13 (Cp); also elsewhere on the board
GND: C5.2, C6.2, C7.2, C8.1, C10.2, C11.2, JP2.3 (G3), R3.2, U4.7 (GND), U5.7 (GND), U6.2 (K), U6.8 (GND), U7.5 (INH), U7.8 (VSS); also elsewhere on the board
unnamed: C9.1, U7.6 (C1)
unnamed: C9.2, U7.7 (C2)
unnamed: C10.1, R2.2
unnamed: C11.1, R1.2, R2.1, U7.9 (VCOin)
unnamed: C15.2, U7.14 (REFin)
unnamed: J3.1, JP1.3 (G3)
unnamed: JP1.2 (G2), U7.3 (COMPin)
unnamed: JP2.2 (G2), U4.5
unnamed: R3.1, U7.11 (R1)
unnamed: R4.2, U4.9, U6.9 (Q)
unnamed: U4.1, U6.3 (J)
unnamed: U4.10, U5.12 (D)
VCC: C5.1, C6.1, C7.1, C8.2, U4.14 (VCC), U5.4 (Sd), U5.14 (VCC), U6.4 (Sd), U6.10 (Sd), U6.11 (J), U6.12 (K), U6.14 (Cd), U6.16 (VCC), U7.16 (VDD); also elsewhere on the board
~AS_7: U4.3, U5.6 (~Q); also elsewhere on the board
~AS_CPU: U4.6; also elsewhere on the board
~DTACK_7: U4.2; also elsewhere on the board
~VMA_7: U5.8 (~Q), U5.10 (Sd); also elsewhere on the board
~VPA_7: U4.8; also elsewhere on the board

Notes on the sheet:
CLK_7
CLK_14
decoupling
QCLK_7
adjust R3 for 50% dutycycle on J2
when HIDE is high ~AS_7~ to the Amiga is not asserted
Jumper JP1: 1-2: PLL generated qaudrature clock (internal) 2-3: motherboard supplied quadrature clock (external) Jumper JP2: 1-2: fast ram populated 2-3: fast ram NOT populated
~Q~ is asserted when D is '1' during a positive clock edge and remains asserted (even when D = '0' during a positive clock edge) until Cd is asserted.

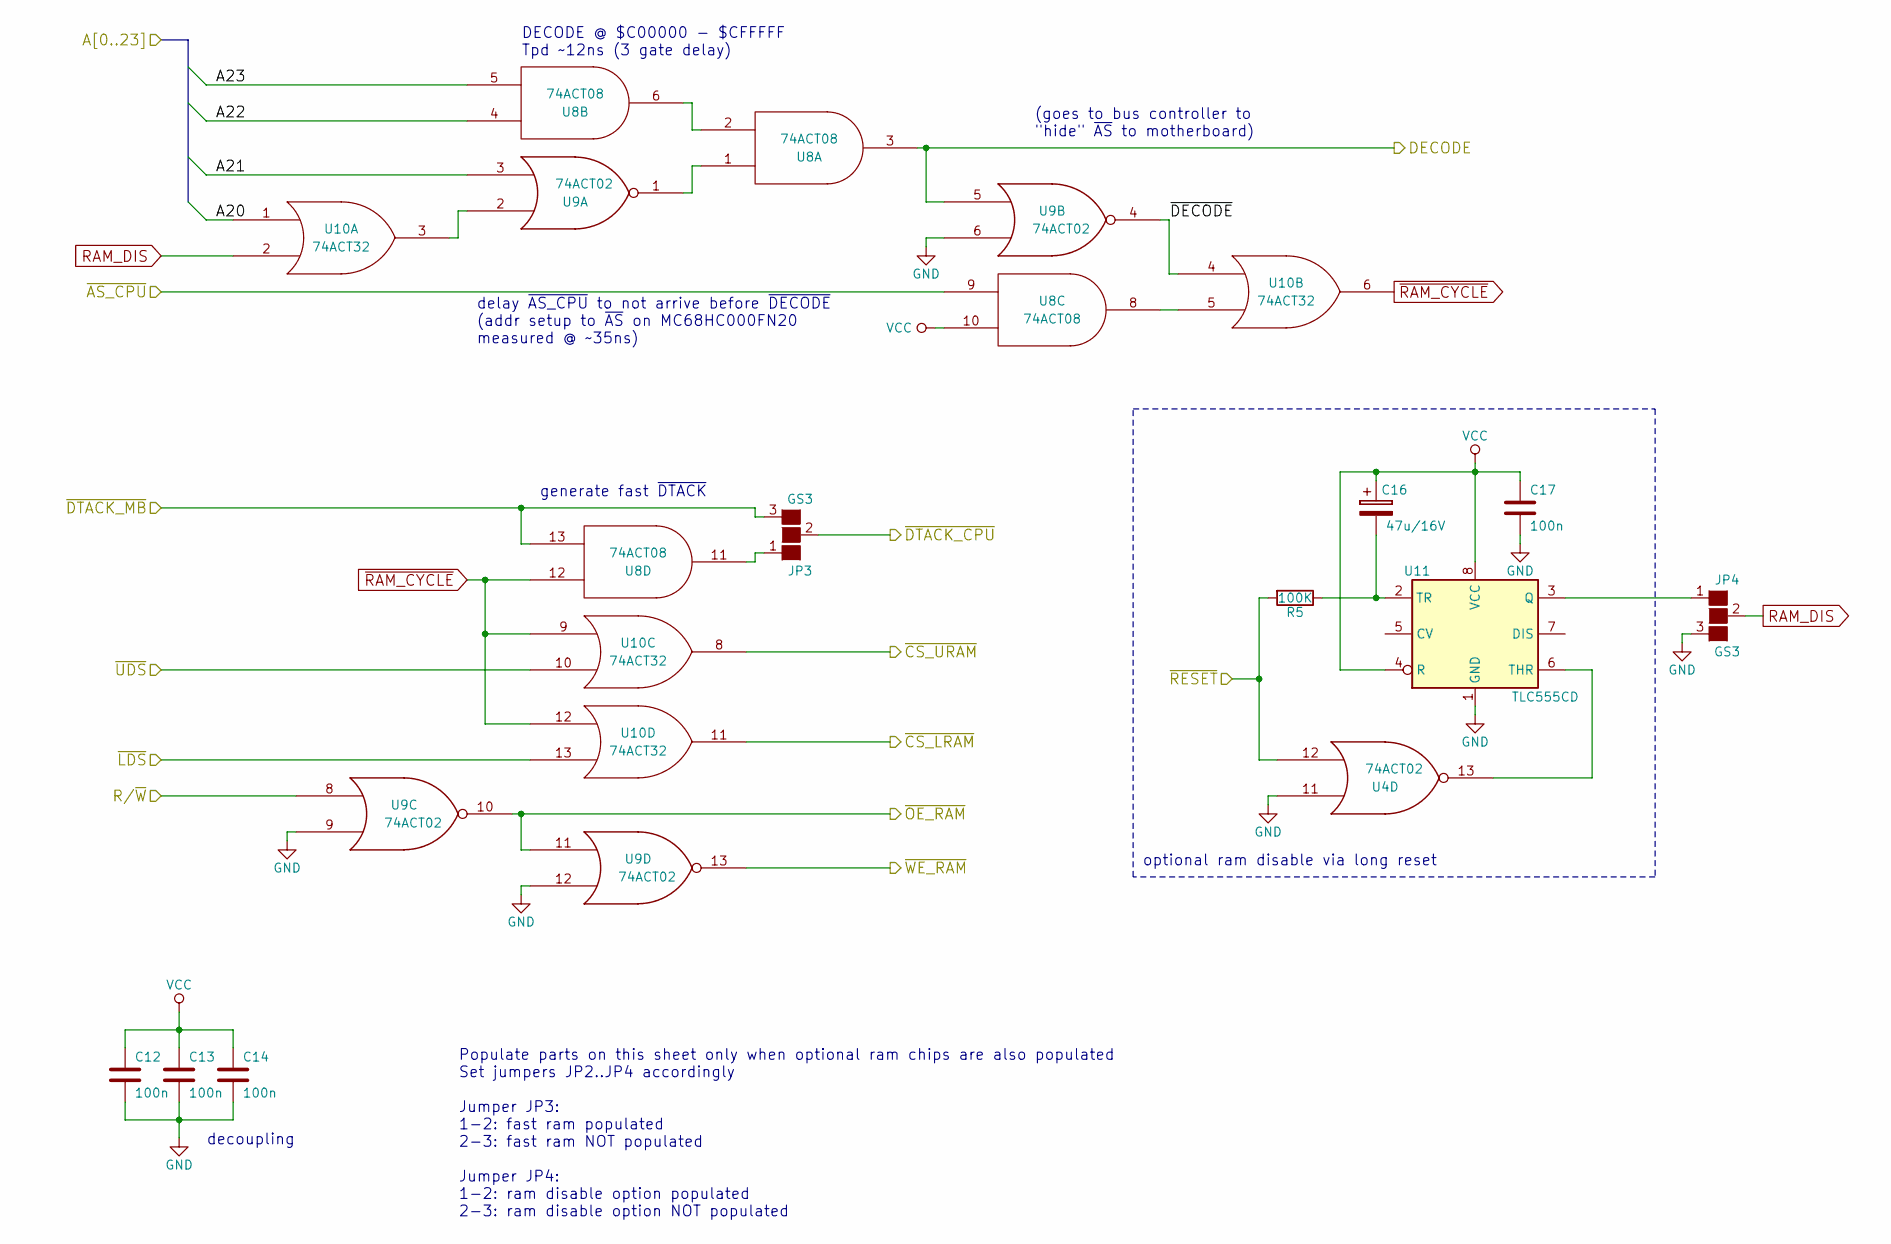
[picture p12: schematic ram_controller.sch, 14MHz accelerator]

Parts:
C12, C13, C14, C17: 100n; C_0805_HandSoldering
C16: 47u/16V; CP_Radial_D6.3mm_P2.50mm
JP3, JP4: GS3
R5: 100K; R_0805_HandSoldering
U4, U9: 74ACT02; SOIC-14_3.9x8.7mm_Pitch1.27mm
U8: 74ACT08; SOIC-14_3.9x8.7mm_Pitch1.27mm
U10: 74ACT32; SOIC-14_3.9x8.7mm_Pitch1.27mm
U11: TLC555CD; SOIC-8_3.9x4.9mm_Pitch1.27mm

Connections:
/bus interface/~DTACK_14: JP3.3 (G3), U8.13; also elsewhere on the board
/fast ram controller/DECODE: U8.3, U9.5; also elsewhere on the board
/fast ram controller/~DECODE: U9.4, U10.4
/~CS_LRAM: U10.11; also elsewhere on the board
/~CS_URAM: U10.8; also elsewhere on the board
/~OE_RAM: U9.10, U9.11; also elsewhere on the board
/~WE_RAM: U9.13; also elsewhere on the board
A20: U10.1; also elsewhere on the board
A21: U9.3; also elsewhere on the board
A22: U8.4; also elsewhere on the board
A23: U8.5; also elsewhere on the board
GND: C12.2, C13.2, C14.2, C17.2, JP4.3 (G3), U4.7 (GND), U4.11, U8.7 (GND), U9.6, U9.7 (GND), U9.9, U9.12, U10.7 (GND), U11.1 (GND); also elsewhere on the board
unnamed: C16.2, R5.1, U11.2 (TR)
unnamed: JP3.1 (G1), U8.11
unnamed: JP4.1 (G1), U11.3 (Q)
unnamed: U8.1, U9.1
unnamed: U8.2, U8.6
unnamed: U9.2, U10.3
unnamed: U8.8, U10.5
unnamed: U4.13, U11.6 (THR)
R/~W: U9.8; also elsewhere on the board
RAM_DIS: JP4.2 (G2), U10.2
VCC: C12.1, C13.1, C14.1, C16.1, C17.1, U4.14 (VCC), U8.10, U8.14 (VCC), U9.14 (VCC), U10.14 (VCC), U11.4 (R), U11.8 (VCC); also elsewhere on the board
~AS_CPU: U8.9; also elsewhere on the board
~DTACK_CPU: JP3.2 (G2); also elsewhere on the board
~LDS: U10.13; also elsewhere on the board
~RAM_CYCLE: U8.12, U10.6, U10.9, U10.12
~RESET~: R5.2, U4.12; also elsewhere on the board
~UDS: U10.10; also elsewhere on the board

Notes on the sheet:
DECODE @ $C00000 - $CFFFFF Tpd ~~12ns (3 gate delay)
delay ~AS_CPU~ to not arrive before ~DECODE~ (addr setup to ~AS~ on MC68HC000FN20 measured @ ~~35ns)
decoupling
optional ram disable via long reset
(goes to bus controller to "hide" ~AS~ to motherboard)
generate fast ~DTACK~
Populate parts on this sheet only when optional ram chips are also populated Set jumpers JP2..JP4 accordingly Jumper JP3: 1-2: fast ram populated 2-3: fast ram NOT populated Jumper JP4: 1-2: ram disable option populated 2-3: ram disable option NOT populated

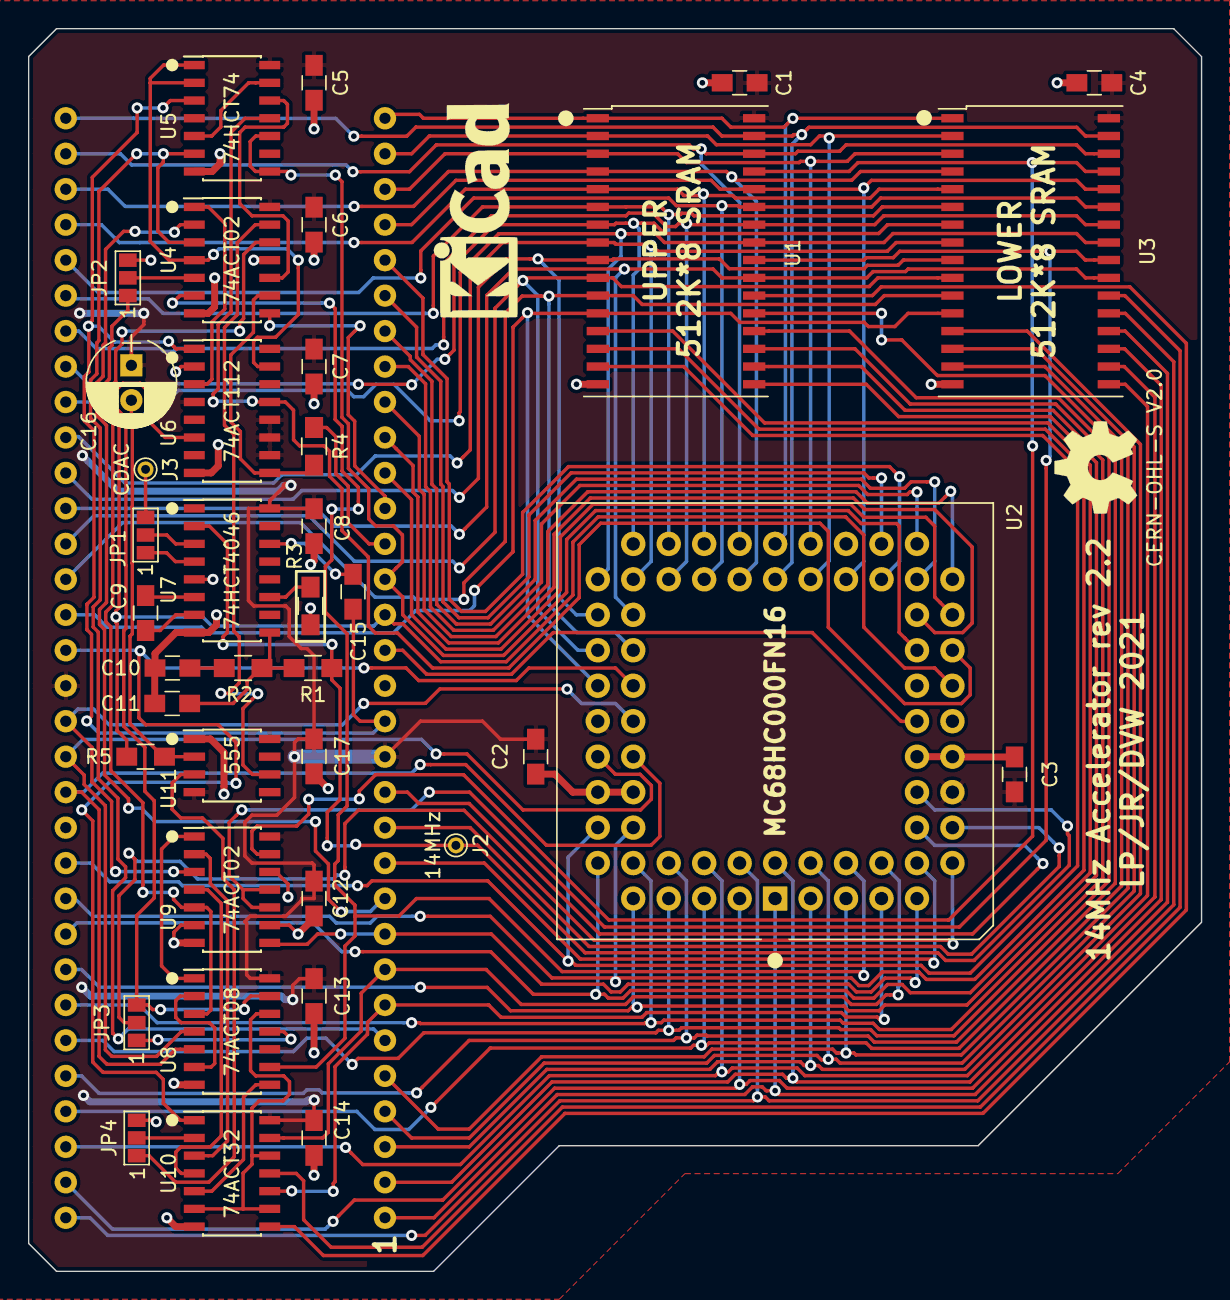
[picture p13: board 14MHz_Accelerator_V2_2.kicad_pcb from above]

Board: 2 copper layers, 84.0 x 89.0 mm, 40 parts (1 on the bottom side), 98 nets.

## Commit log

2021-06-30 Added KiCad files
    [14MHz_Accelerator_V2_2.kicad_pcb, 14MHz_Accelerator_V2_2.sch, bus_interface.sch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]
2021-07-03 minor layout optimizations
    added bill of materials
    added pictures
    [14MHz_Accelerator_V2_2-B.Cu.gbl, 14MHz_Accelerator_V2_2-B.Mask.gbs, 14MHz_Accelerator_V2_2-B.SilkS.gbo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]
2021-07-03 Added license
    Added schematics in PDF format
2021-08-01 added remark that SRAM must be a 5V type
